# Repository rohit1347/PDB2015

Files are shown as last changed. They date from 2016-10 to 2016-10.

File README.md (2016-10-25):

# PDB2015
Final Power Distribution Board used by SRM Team ROBOCON for the ROBOCON 2015 competition.

Features-
- Buck voltage regulators for 5V o/p.
- Linear voltage regulators for 5V, 9V, 12V o/p.
- Diode having high forward current capacity. This diode is used for preventing back current flow caused by motors.
- MOSFETs to be used as simple switches.
- Fuses to prevent high current usage.
- XT60 connector to connect with LIPO cell.
- 2 layered PCB.
- Designed on EAGLE CAD.

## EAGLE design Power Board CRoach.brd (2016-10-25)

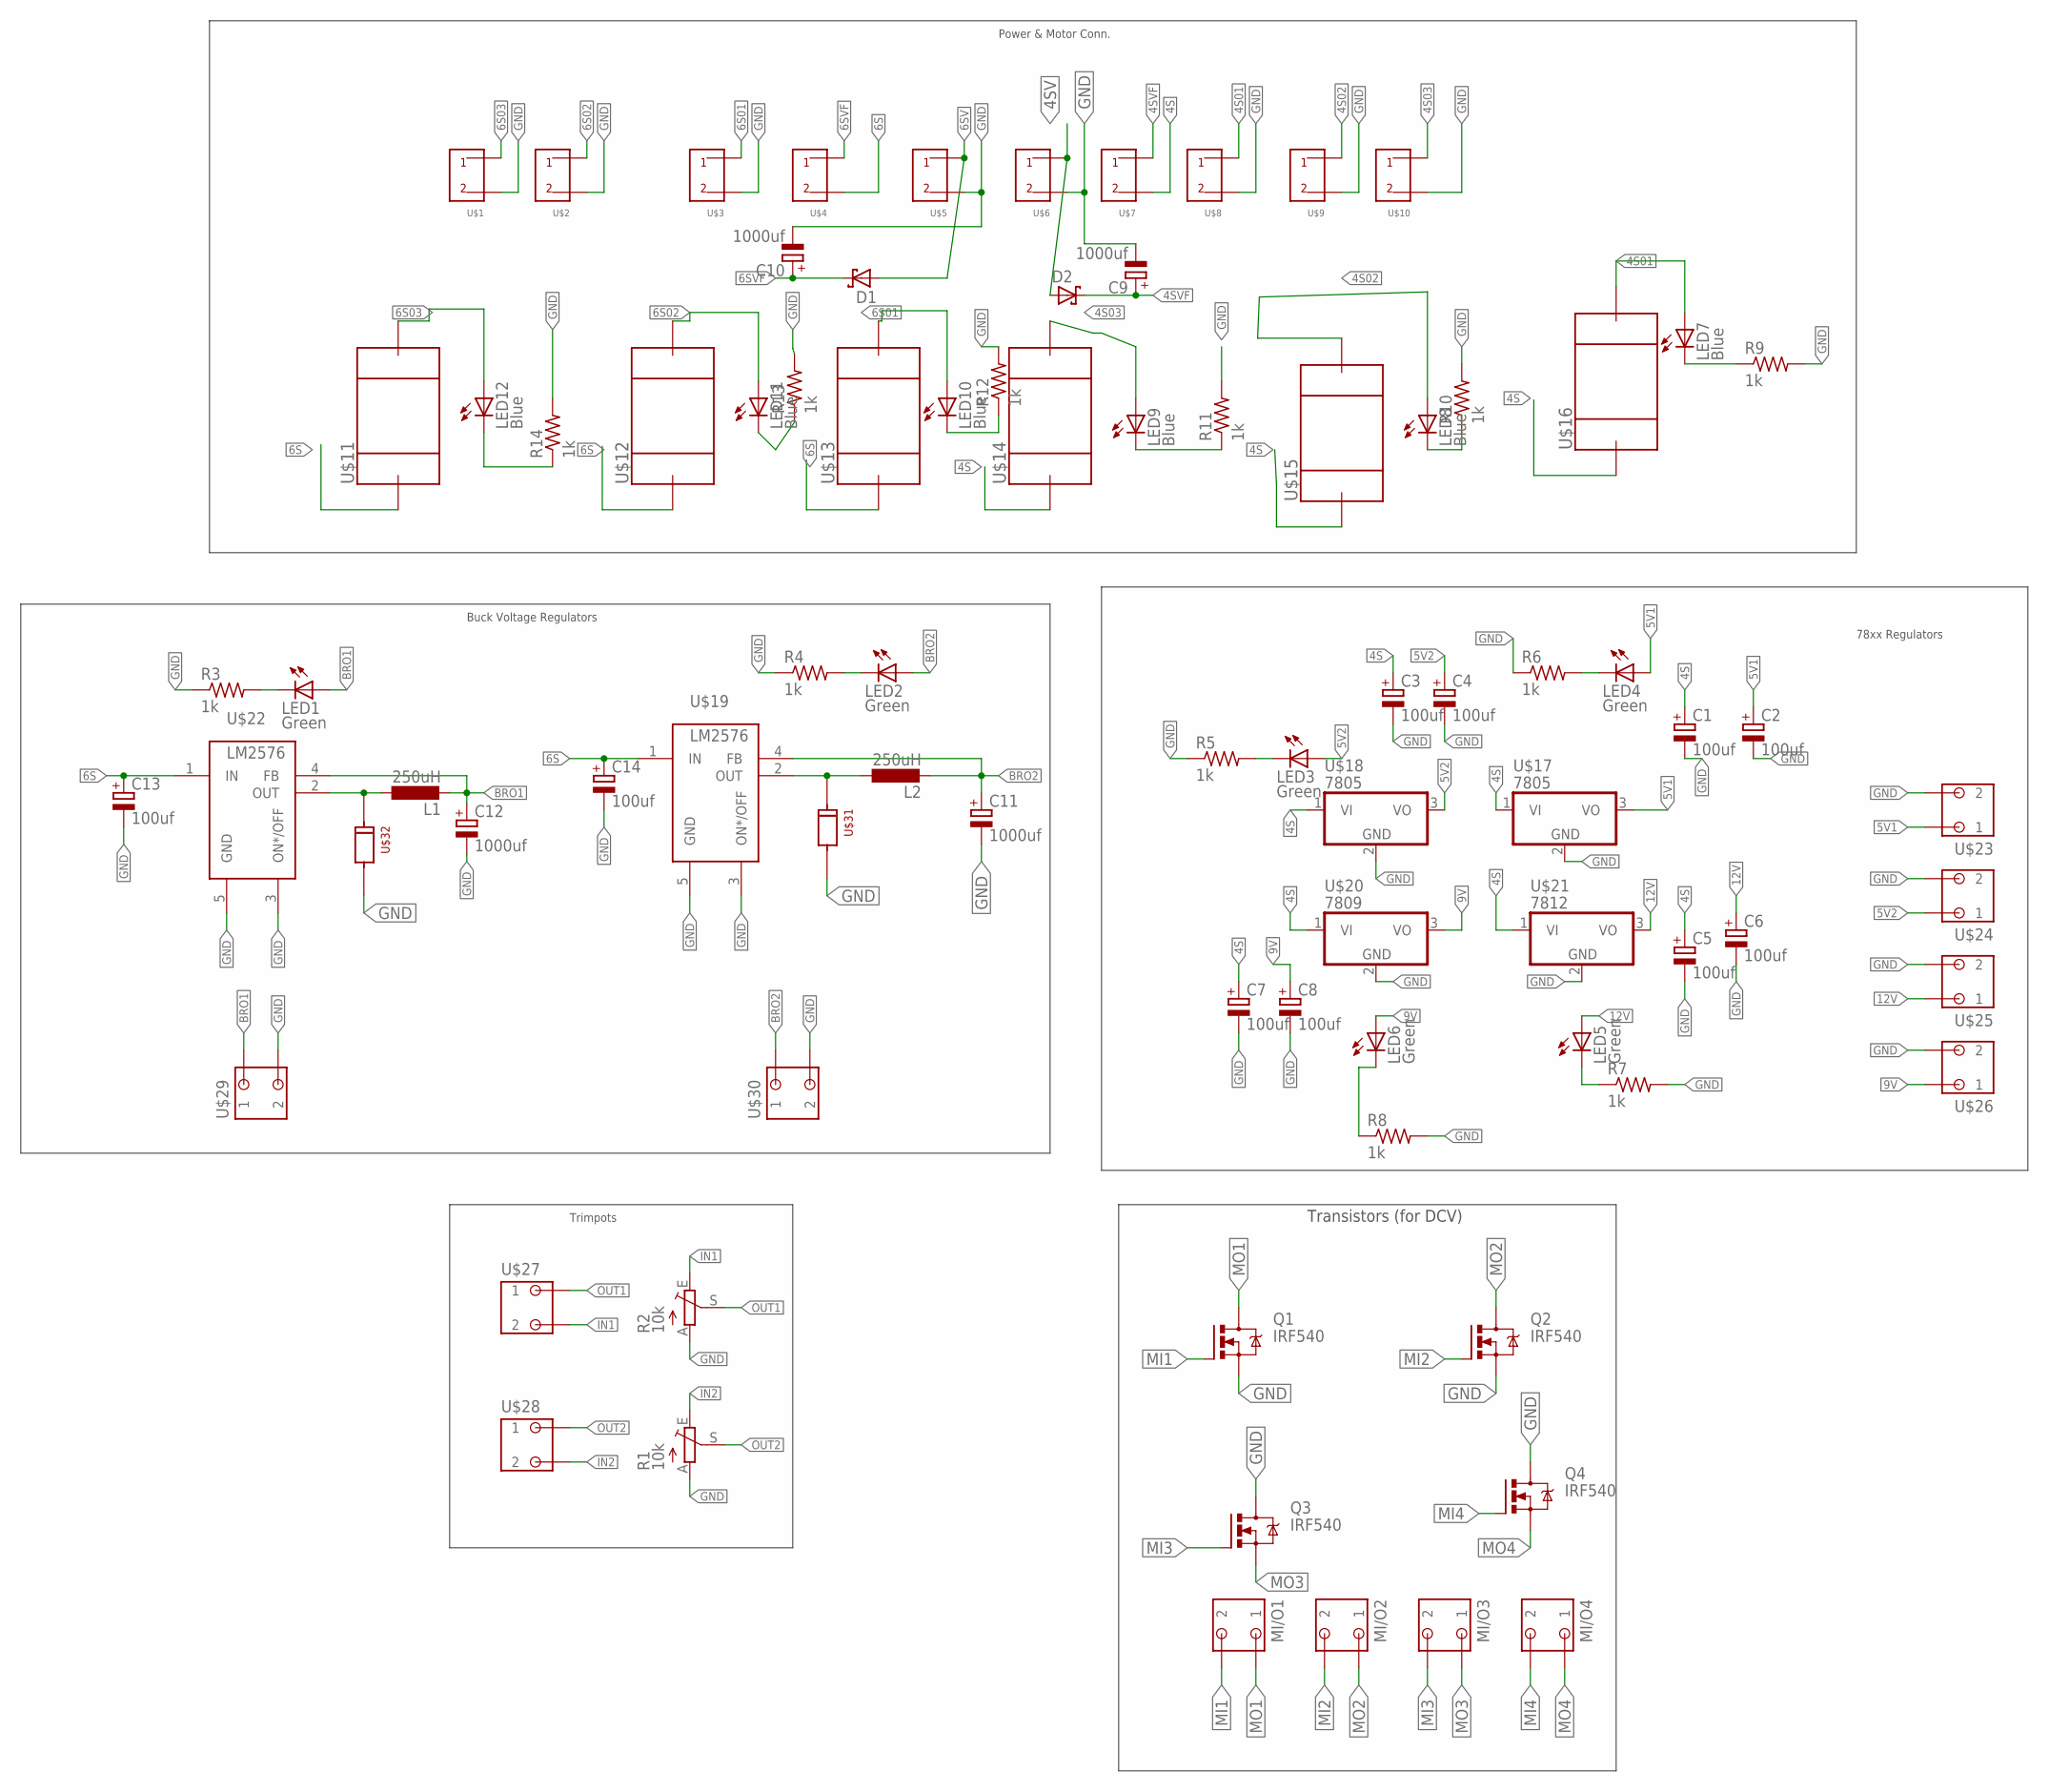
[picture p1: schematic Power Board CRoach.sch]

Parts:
C1, C2, C3, C4, C5, C6, C7, C8: 100uf; E2-5
C9, C10, C11, C12: 1000uf; E7,5-16
C13, C14: 100uf; E2,5-5
D1, D2: SCHOTTKY-DIODEP6T15; P6T15
L1, L2: 250uH; 0204/7
LED1, LED2, LED3, LED4, LED5, LED6: Green; LED5MM
LED7, LED8, LED9, LED10, LED11, LED12: Blue; LED5MM
MI/O1, MI/O2, MI/O3, MI/O4: SPTBB2-A2; SPTB
Q1, Q2, Q3, Q4: IRF540; TO220BV
R1, R2: 10k; CA6V
R3, R4, R5, R6, R7, R8, R9, R10, R11, R12, R13, R14: 1k; 0204/7
U$1, U$2, U$3, U$4, U$5, U$6, U$7, U$8, U$9, U$10: SCREW_XT-60
U$11, U$12, U$13, U$14, U$15, U$16: CPT-FUSE; CPT-FUSES
U$17, U$18: 7805; 78XX
U$19, U$22: LM2576
U$20: 7809; 78XX
U$21: 7812; 78XX
U$23, U$24, U$27, U$28: SPTBB2-A1; SPTB
U$25, U$26, U$29, U$30: SPTBA2-B1; SPTB
U$31, U$32: 1N5822

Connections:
4S: C1.+, C3.+, C5.+, C7.+, U$7.P$2, U$14.P$1, U$15.P$1, U$16.P$1, U$17.1 (VI), U$18.1 (VI), U$20.1 (VI), U$21.1 (VI)
4S01: LED7.A, U$8.P$1, U$16.P$2
4S02: LED8.A, U$9.P$1, U$15.P$2
4S03: LED9.A, U$10.P$1, U$14.P$2
4SV: D2.A, U$6.P$1
4SVF: C9.+, D2.C, U$7.P$1
5V1: C2.+, LED4.A, U$17.3 (VO), U$23.B2 (1)
5V2: C4.+, LED3.A, U$18.3 (VO), U$24.B2 (1)
6S: C13.+, C14.+, U$4.P$2, U$11.P$1, U$12.P$1, U$13.P$1, U$19.1 (IN), U$22.1 (IN)
6S01: LED10.A, U$3.P$1, U$13.P$2
6S02: LED11.A, U$2.P$1, U$12.P$2
6S03: LED12.A, U$1.P$1, U$11.P$2
6SV: D1.A, U$5.P$1
6SVF: C10.+, D1.C, U$4.P$1
9V: C8.+, LED6.A, U$20.3 (VO), U$26.A2 (1)
12V: C6.+, LED5.A, U$21.3 (VO), U$25.A2 (1)
BRO1: C12.+, L1.2, LED1.A, U$22.4 (FB), U$29.A2 (1)
BRO2: C11.+, L2.2, LED2.A, U$19.4 (FB), U$30.A2 (1)
GND: C1.-, C2.-, C3.-, C4.-, C5.-, C6.-, C7.-, C8.-, C9.-, C10.-, C11.-, C12.-, C13.-, C14.-, Q1.S, Q2.S, Q3.D, Q4.D, R1.A, R2.A, R3.1, R4.1, R5.1, R6.1, R7.2, R8.2, R9.2, R10.2, R11.2, R12.2, R13.2, R14.2, U$1.P$2, U$2.P$2, U$3.P$2, U$5.P$2, U$6.P$2, U$8.P$2, U$9.P$2, U$10.P$2, U$17.2 (GND), U$18.2 (GND), U$19.3 (ON*/OFF), U$19.5 (GND), U$20.2 (GND), U$21.2 (GND), U$22.3 (ON*/OFF), U$22.5 (GND), U$23.A1 (2), U$24.A1 (2), U$25.B1 (2), U$26.B1 (2), U$29.B1 (2), U$30.B1 (2), U$31.-, U$32.-
IN1: R2.E, U$27.A1 (2)
IN2: R1.E, U$28.A1 (2)
MI1: MI/O1.A2 (2), Q1.G
MI2: MI/O2.A2 (2), Q2.G
MI3: MI/O3.A2 (2), Q3.G
MI4: MI/O4.A2 (2), Q4.G
MO1: MI/O1.B2 (1), Q1.D
MO2: MI/O2.B2 (1), Q2.D
MO3: MI/O3.B2 (1), Q3.S
MO4: MI/O4.B2 (1), Q4.S
unnamed: LED7.K (C), R9.1
unnamed: LED8.K (C), R10.1
unnamed: LED9.K (C), R11.1
unnamed: LED10.K (C), R12.1
unnamed: LED11.K (C), R13.1
unnamed: LED12.K (C), R14.1
unnamed: L1.1, U$22.2 (OUT), U$32.+
unnamed: L2.1, U$19.2 (OUT), U$31.+
unnamed: LED5.K (C), R7.1
unnamed: LED6.K (C), R8.1
unnamed: LED3.K (C), R5.2
unnamed: LED4.K (C), R6.2
unnamed: LED2.K (C), R4.2
unnamed: LED1.K (C), R3.2
OUT1: R2.S, U$27.B2 (1)
OUT2: R1.S, U$28.B2 (1)

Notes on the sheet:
78xx Regulators
Trimpots
Power & Motor Conn.
Buck Voltage Regulators
Transistors (for DCV)

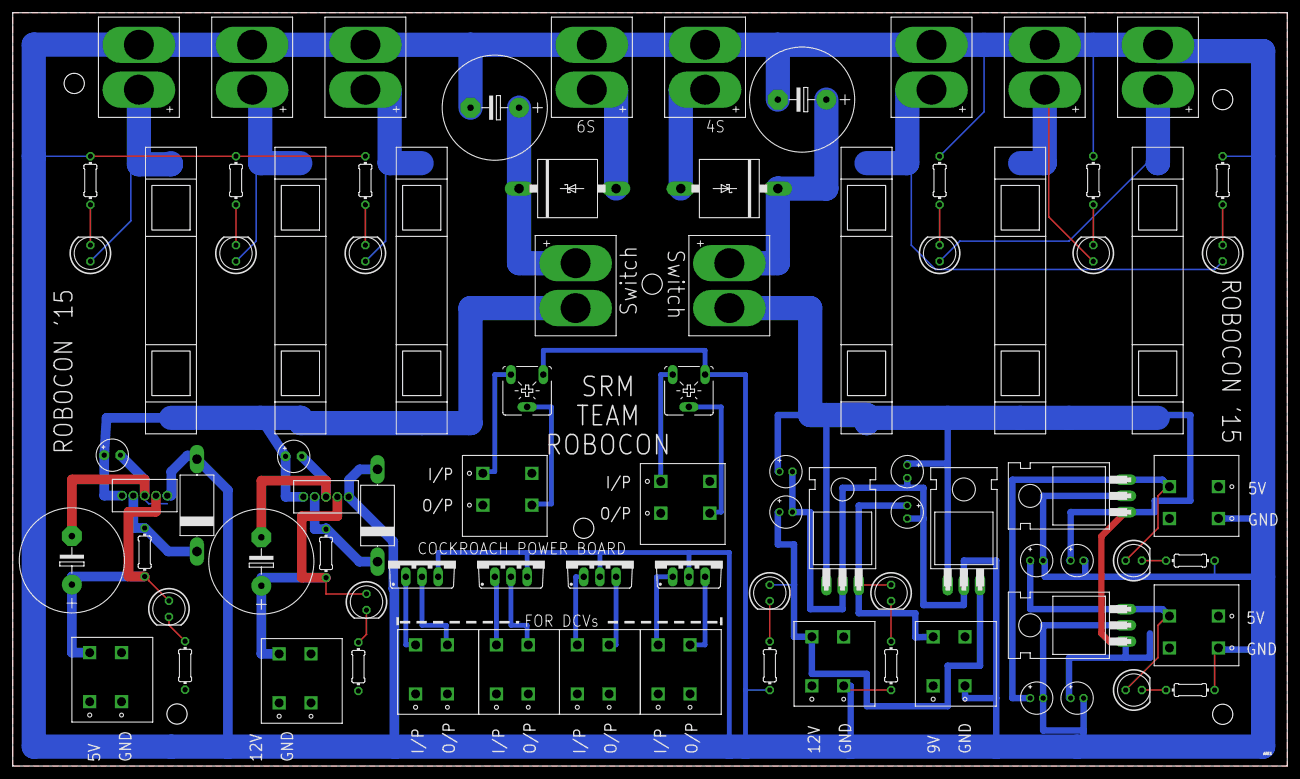
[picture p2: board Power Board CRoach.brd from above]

Board: 2 copper layers, 200.1 x 118.3 mm, 84 parts (0 on the bottom side), 45 nets.
